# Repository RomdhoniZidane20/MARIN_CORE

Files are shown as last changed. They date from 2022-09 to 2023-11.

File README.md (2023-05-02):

# MARIN Core
ICHIRO Controller Manager Board for Dynamixel
## Features

* RS485/TTL on 4 Buses
* BNO055 IMU Sensor With Absolute Orientation
* Hot Swap switching System for Mini PC (Intel NUC 10th)
* Motor Voltage Power Switch System

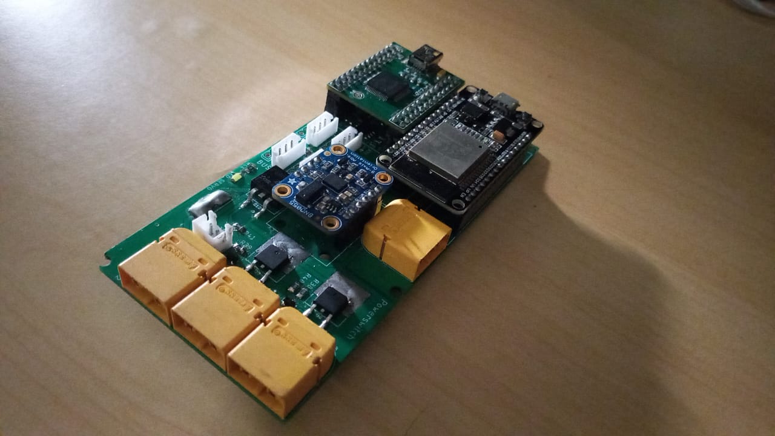
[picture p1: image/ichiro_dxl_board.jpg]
ichiro_dxl_board ICHIRO_DXL_BOARD


## Include Hardware and Software setup for dxl_board

Documentations for [FT4232_dxl](https://github.com/RomdhoniZidane20/ichiro_dxl_board/tree/main/firmware/FT4232)

Documentations for [MARIN_CORE](https://github.com/RomdhoniZidane20/ichiro_dxl_board/tree/main/firmware/Marin_Core_Firmware)

Documentations for [Loadcel_dxl](https://github.com/RomdhoniZidane20/ichiro_dxl_board/tree/main/firmware/Loadcell)

Documentations for [Interface_dxl](https://github.com/RomdhoniZidane20/ichiro_dxl_board/tree/main/firmware/Interface)

## License 
The FT4232 and ADM3078E eagle library of this repository based on 
"SUSTAINA-OP" by [Masato Kubotera](https://github.com/MasatoKubotera) is licensed under [ CC BY-NC-SA 4.0](https://creativecommons.org/licenses/by-nc-sa/4.0/).

CC BY-NC-SA 4.0


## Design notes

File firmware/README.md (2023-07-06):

# NOTE MASTER

## 15 September 2022

    1. Untuk program slave saat ini masih belum bisa bulkread maupun syncwrite  !!!
    2. Testing dengan protocol1.0 .
    3. Bulkread maupun snycwrite ditanggulani oleh latency timer usb menjadi 1 ms, maksimal latency yang bisa dicapai hingga 0 ms. (command : $ echo 1 | sudo tee /sys/bus/usb-serial/devices/ttyUSB0/latency_timer).
    4. Servo tidak bisa menjadi satu bus dengan slave esp karena akan terjadi masalah jika daya servo fail atau mati, paket akan error dan mengganggu paket yang dikirim oleh slave ke master (PC).
    
## 17 Januari 2023
    1. Slave BulkRead pada dynamixel2arduino slave upgrade memiliki maksimal panjang len address 6 byte. (PADA PROTOCOL 1.0)
    2. Jika bulkread address khusus read harus urut
    3. BELUM SUPPORT SYNCWRITE

## 25 Januari 2023
    1. Bulkread hanya bisa dibaca pada satu variabel array yang sama.
    2. Agar dapat dibaca Bulkread, pengiriman data paket dari firmware harus melalui satu array untuk pembacaan datanya.
    3. Sudah dapat membaca lebih dari 12 len address. 
    4. TODO syncwrite !!

## 6 Juli 2023
    1. Device Slave pada Dyanmixel2Arduino memiliki Return Delay sekitar 500us - 700us.
    2. TODO : mengecek berbagai rangkaian hardwware -> 1. Test pada ESP32 dengan Logic Level Converter
                                                       2. Test pada ESP32 dengan rankaian pembagi tegangan
                                                       3. Test pada ESP32 v4.
                                                       4. Test pada STM32 Blackpill.

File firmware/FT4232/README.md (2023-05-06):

# FIRMWARE

## Flash to correct EEPROM:
Install drivers from https://www.ftdichip.com/Drivers/D2XX.htm 

Unpack them:
```tar -xvf libftd2xx-x86_64-1.4.xx.gz```

Copy them into the library folder:
```sudo cp -r release/build/lib* /usr/local/lib```

Link them:
```sudo ln -s /usr/local/lib/libftd2xx.so.1.4.xx /usr/local/lib/libftd2xx.so```

Make them executable:
```sudo chmod 0755 /usr/local/lib/libftd2xx.so.1.4.xx```

Unload Serial USB Drivers (these will be reloaded when the device is removed and plugged back in)
```sudo rmmod ftdi_sio usbserial ```

compile code (in the firmware directory):
```gcc -o write main.c -L. -lftd2xx -Wl,-rpath,/usr/local/lib```

remove and plug in the device and it should appear as 4 virtual serial ports

## Source
This Firmware based on Bit-Bots [QUADDXL](https://github.com/bit-bots/bitbots_quaddxl) repository.

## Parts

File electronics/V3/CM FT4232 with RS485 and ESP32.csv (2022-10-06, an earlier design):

Qty | Value | Device | Package | Parts | Description | AVAILABILITY | DESCRIPTION | MF | MP | MPN | OC_FARNELL | OC_NEWARK | PACKAGE | POPULARITY | PRICE | PROD_ID | PURCHASE-URL | SPICEPREFIX | VALUE
2 |  | LEDCHIPLED_0805 | CHIPLED_0805 | LED_PC, LED_SERVO | LED |  |  |  |  |  |  |  |  | 52
37 |  | RESISTOR0805 | 0805 | R1, R2, R3, R4, R5, R6, R7, R8, R9, R10, R11, R12, R13, R14, R15, R16, R17, R18, R19, R20, R21, R22, R23, R24, R25, R26, R27, R28, R29, R30, R31, R32, R33, R34, R35, R36, R37 | Generic Resistor Package
1 | 100uF | CPOL-EU153CLV-1010 | 153CLV-1010 | C5 | POLARIZED CAPACITOR, European symbol |  |  |  |  |  |  |  |  | 0 |  |  |  | C
5 | 10K | R-US_M0805 | M0805 | R38, R39, R40, R41, R43 | RESISTOR, American symbol |  |  |  |  |  |  |  |  | 45 |  |  |  | R
2 | 1808_FUSE_HOLDER | 1808_FUSE_HOLDER | 1808_FUSE_HOLDER | U$3, U$4
1 | 1K | R-EU_R1206 | R1206 | R46 | RESISTOR, European symbol |  |  |  |  |  |  |  |  | 41 |  |  |  | R
2 | 200mA/40V | TRANS_PNP-PMBT3906|MMBT3906L | SOT23-3 | Q10, Q11 | PNP transistor |  |  |  |  |  |  |  |  |  |  | TRANS-08052 |  |  | 200mA/40V
4 | 22-03-5035 | 22-03-5035 | 5267-3 | J1, J2, J3, J4 | Molex SPOX Vert, Tin (Dynamixel AX/MX Bus)
4 | 22-03-5045 | 22-03-5045 | 5267-4 | J5, J6, J7, J8 | Molex SPOX Vert, Tin (Dynamixel RX Bus)
1 | 22-23-2021 | 22-23-2021 | 22-23-2021 | X8 | .100 (2.54mm) Center Header - 2 Pin" |  |  | MOLEX |  | 22-23-2021 | 1462926 | 25C3832 |  | 40
1 | 22-23-2041 | 22-23-2041 | 22-23-2041 | X1 | .100 (2.54mm) Center Header - 4 Pin" |  |  | MOLEX |  | 22-23-2041 | 1462920 | 38C0355 |  | 21
1 | 22-23-2071 | 22-23-2071 | 22-23-2071 | X2 | .100 (2.54mm) Center Header - 7 Pin" |  |  | MOLEX |  | 22-23-2071 | 1654534 | 56H0445 |  | 1
1 | 220uF | CPOL-EUUD-6,3X8,8 | UD-6,3X5,8_NICHICON | C6 | POLARIZED CAPACITOR, European symbol |  |  |  |  |  |  |  |  | 0 |  |  |  | C
2 | 2K | R-US_M0805 | M0805 | R42, R44 | RESISTOR, American symbol |  |  |  |  |  |  |  |  | 45 |  |  |  | R
1 | 33uH | CDRH127/LDNP-470MC | IND_CDRH127/LDNP-470MC_SUM | L1 | Check availability | In Stock | 47 µH Shielded - Inductor 3.25 A 78mOhm Max Nonstandard | Sumida America | CDRH127/LDNP-470MC |  |  |  | Nonstandard Sumida |  | None |  | https://pricing.snapeda.com/search/part/CDRH127/LDNP-470MC/?ref=eda
1 | 3K | R-EU_R1206 | R1206 | R45 | RESISTOR, European symbol |  |  |  |  |  |  |  |  | 41 |  |  |  | R
1 | 600mA/40V | TRANS_NPN-MMBT2222AL | SOT23-3 | Q1 | NPN transistor |  |  |  |  |  |  |  |  |  |  | TRANS-08049 |  |  | 600mA/40V
5 | ADM3078E | ADM3078E | ADM3078E | IC1, IC2, IC3, IC4, IC5
1 | BNO055 | BNO055 | BNO055 | U$2
1 | BOB-12009 | BOB-12009 | CONV_BOB-12009 | U2 | Logic Level Converter - Bi-Direc Check availability | In Stock | BSS138 Logic-Level Translator Interface Evaluation Board | SparkFun | BOB-12009 |  |  |  | None |  | None |  | https://pricing.snapeda.com/search/part/BOB-12009/?ref=eda
1 | ESP32DEVKITV1 | ESP32DEVKITV1 | ESP32-DEVKITV1 | U$1
1 | FT4232H_MINI_MODULE | FT4232H_MINI_MODULE | FT4232H_MINI_MODULE | M1
1 | LM2596S | LM2596S | TO263-5 | IC6 | SIMPLE SWITCHER® Power Converter 150 kHz 3A Step-Down Voltage Regulator |  |  | NATIONAL SEMICONDUCTOR |  | LM2596S-ADJ/NOPB | 9494367 | 41K3842 |  | 12
4 | SQM40P10-40L_GE3 | SQM40P10-40L_GE3 | TO-252-3 | Q7, Q8, Q9, Q12
1 | SS34 | SS34 | DIOM6859X262N | D1 | Check availability | In Stock | 3A, 40V, Schottky Rectifier | Taiwan Semiconductor | SS34 |  |  |  | SMC-2 Taiwan Semiconductor |  | None |  | https://pricing.snapeda.com/search/part/SS34/?ref=eda
4 | XT60PW-M | XT60PW-M | XT60PW-M | BATT_3, BATT_4, BATT_CM1, PC1

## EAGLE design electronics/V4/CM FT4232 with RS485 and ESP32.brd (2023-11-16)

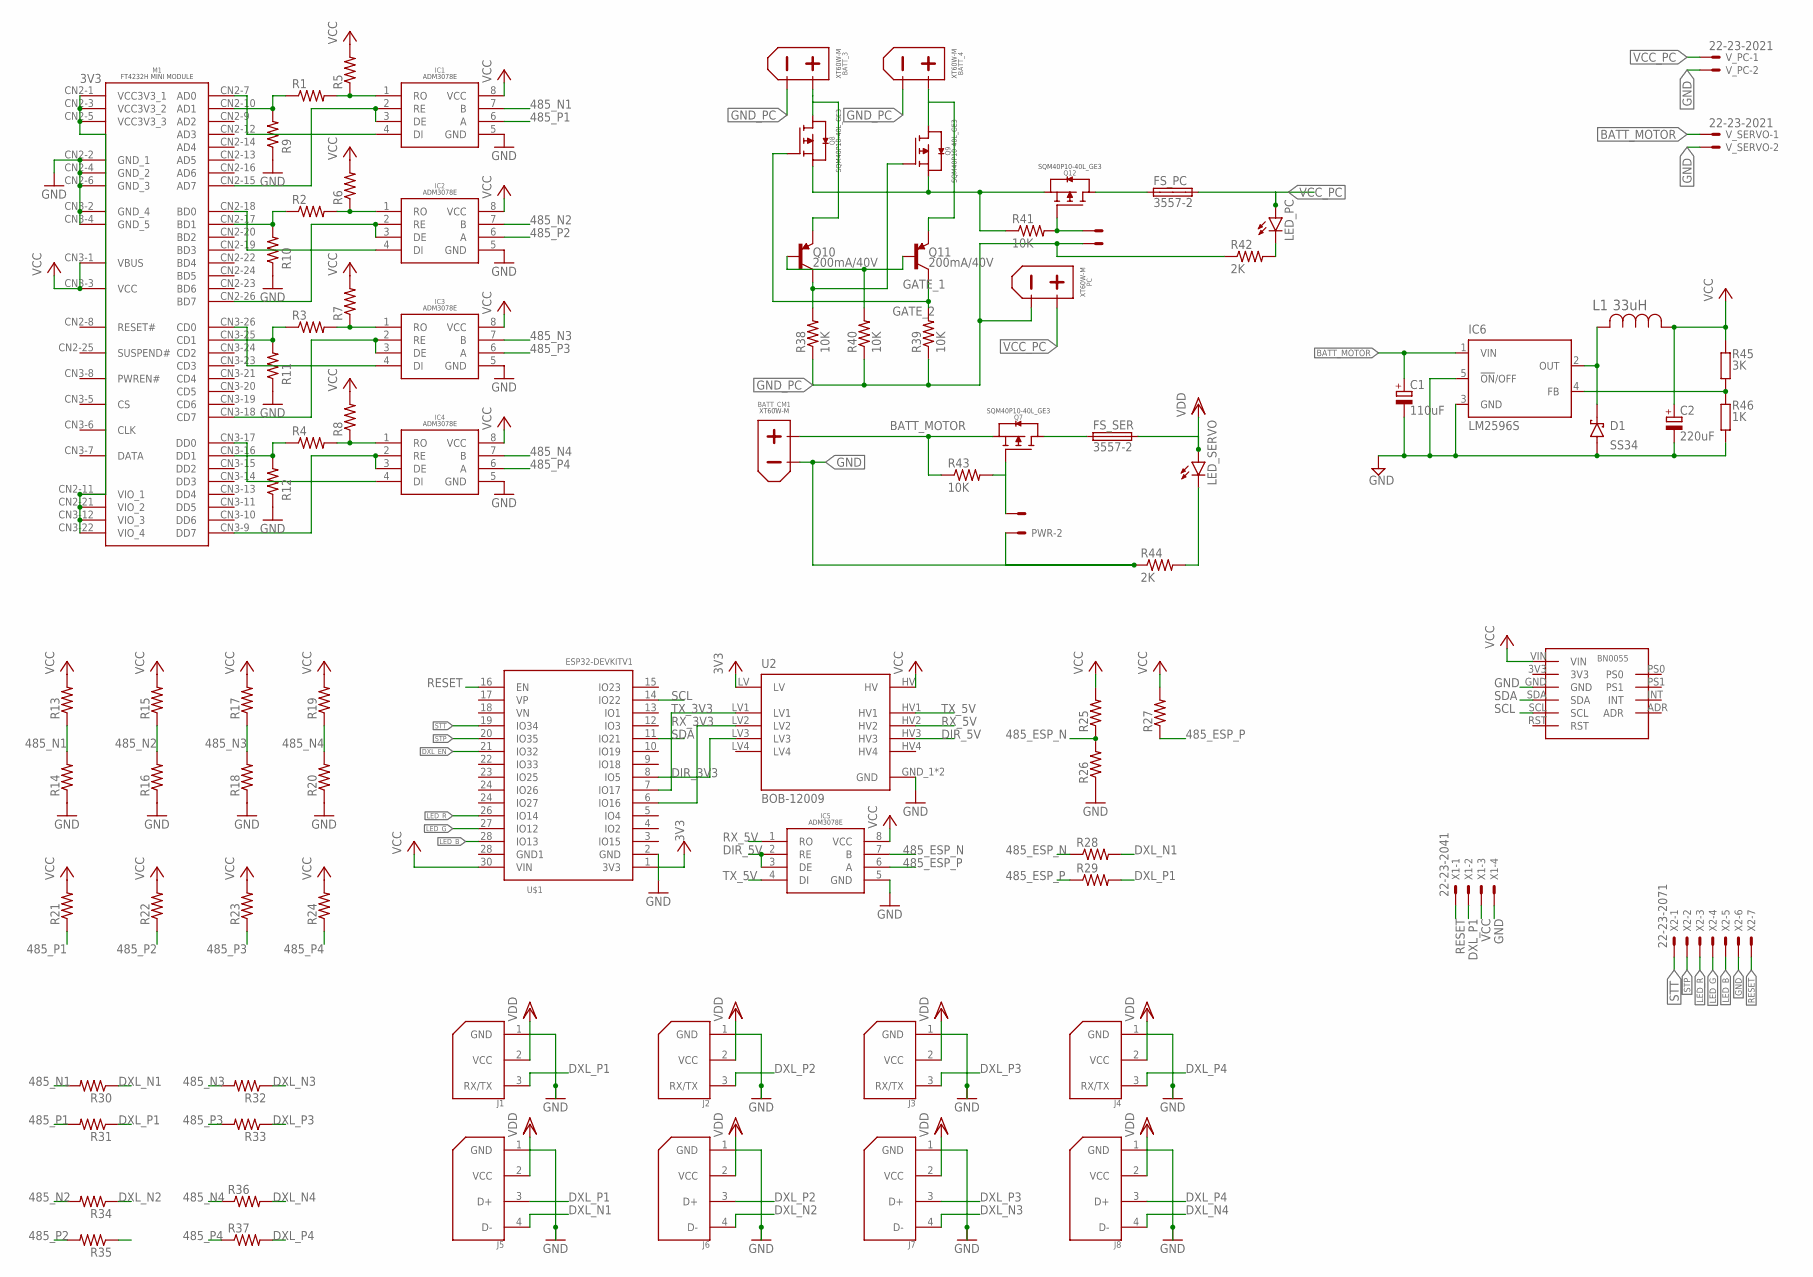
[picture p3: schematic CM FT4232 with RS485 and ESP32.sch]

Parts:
BATT_3, BATT_4: XT60PW-M
BATT_CM1: XT60PW-M
C1: 110uF; E2,5-6
C2: 220uF; E2,5-6
D1: SS34; DIOM6859X262N
FS_PC: 3557-2; FUSE_3557-2
FS_SER: 3557-2; FUSE_3557-2
IC1, IC2, IC3, IC4, IC5: ADM3078E
IC6: LM2596S; TO263-5
J1, J2, J3, J4: 22-03-5035; 5267-3
J5, J6, J7, J8: 22-03-5045; 5267-4
L1: 33uH; IND_CDRH127/LDNP-470MC_SUM
LED_PC: LEDCHIPLED_0805; CHIPLED_0805
LED_SERVO: LEDCHIPLED_0805; CHIPLED_0805
M1: FT4232H_MINI_MODULE
PC: XT60PW-M
PWR: 22-23-2021
Q7, Q8, Q9, Q12: SQM40P10-40L_GE3; TO-252-3
Q10, Q11: 200mA/40V; SOT23-3
R1, R2, R3, R4, R5, R6, R7, R8, R9, R10, R11, R12, R13, R14, R15, R16, R17, R18, R19, R20, R21, R22, R23, R24, R25, R26, R27, R28, R29, R30, R31, R32, R33, R34, R35, R36, R37: 0805
R38, R39, R40, R41, R43: 10K; M0805
R42, R44: 2K; M0805
R45: 3K; R1206
R46: 1K; R1206
SW_PC: 22-23-2021
U2: BOB-12009; CONV_BOB-12009
U$1: ESP32DEVKITV1; ESP32-DEVKITV1
U$2: BNO055
V_PC: 22-23-2021
V_SERVO: 22-23-2021
X1: 22-23-2041
X2: 22-23-2071

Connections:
3V3: M1.CN2-1 (VCC3V3_1), M1.CN2-3 (VCC3V3_2), M1.CN2-5 (VCC3V3_3), M1.CN2-11 (VIO_1), M1.CN2-21 (VIO_2), M1.CN3-12 (VIO_3), M1.CN3-22 (VIO_4), U2.LV, U$1.1 (3V3)
485_ESP_N: IC5.7 (B), R25.1, R26.2, R28.1
485_ESP_P: IC5.6 (A), R27.1, R29.1
485_N1: IC1.7 (B), R13.1, R14.2, R30.2
485_N2: IC2.7 (B), R15.1, R16.2, R34.2
485_N3: IC3.7 (B), R17.1, R18.2, R32.2
485_N4: IC4.7 (B), R19.1, R20.2, R36.1
485_P1: IC1.6 (A), R21.1, R31.2
485_P2: IC2.6 (A), R22.1, R35.2
485_P3: IC3.6 (A), R23.1, R33.2
485_P4: IC4.6 (A), R24.1, R37.1
+3: Q8.3 (S), Q9.3 (S), Q12.3 (S), R41.1
BATT_MOTOR: BATT_CM1.+, C1.+, IC6.1 (VIN), Q7.3 (S), R43.1, V_SERVO.1
DI1: IC1.4 (DI), M1.CN2-7 (AD0)
DIR_3V3: U2.LV3, U$1.8 (IO5)
DIR_5V: IC5.2 (RE), IC5.3 (DE), U2.HV3
DXL_EN: U$1.21 (IO32)
DXL_N1: J5.4 (D-), R28.2, R30.1
DXL_N2: J6.4 (D-), R34.1
DXL_N3: J7.4 (D-), R32.1
DXL_N4: J8.4 (D-), R36.2
DXL_P1: J1.3 (RX/TX), J5.3 (D+), R29.2, R31.1, X1.2
DXL_P2: J2.3 (RX/TX), J6.3 (D+), R35.1
DXL_P3: J3.3 (RX/TX), J7.3 (D+), R33.1
DXL_P4: J4.3 (RX/TX), J8.3 (D+), R37.2
GATE_1: Q9.1 (G), Q10.3 (C), R38.2
GATE_2: Q8.1 (G), Q11.3 (C), R39.2
GND: BATT_CM1.1 (-), BATT_CM1.2 (-), BATT_CM1.-, C1.-, C2.-, D1.A, IC1.5 (GND), IC2.5 (GND), IC3.5 (GND), IC4.5 (GND), IC5.5 (GND), IC6.3 (GND), IC6.5 (!ON!/OFF), J1.1 (GND), J2.1 (GND), J3.1 (GND), J4.1 (GND), J5.1 (GND), J6.1 (GND), J7.1 (GND), J8.1 (GND), M1.CN2-2 (GND_1), M1.CN2-4 (GND_2), M1.CN2-6 (GND_3), M1.CN3-2 (GND_4), M1.CN3-4 (GND_5), PWR.2, R9.1, R10.1, R11.1, R12.1, R14.1, R16.1, R18.1, R20.1, R26.1, R44.1, R46.1, U2.GND_1 (GND), U2.GND_2 (GND), U$1.2 (GND), U$2.GND, V_PC.2, V_SERVO.2, X1.4, X2.6
GND_PC: BATT_3.1 (-), BATT_3.2 (-), BATT_3.-, BATT_4.1 (-), BATT_4.2 (-), BATT_4.-, PC.1 (-), PC.2 (-), PC.-, R38.1, R39.1, R40.1, R42.1, SW_PC.2
LED_B: U$1.28 (IO13), X2.5
LED_G: U$1.27 (IO12), X2.4
LED_R: U$1.26 (IO14), X2.3
unnamed: FS_PC.1 (1A), Q12.4 (D)
unnamed: IC2.2 (RE), IC2.3 (DE), M1.CN2-26 (BD7)
unnamed: IC3.2 (RE), IC3.3 (DE), M1.CN3-18 (CD7)
unnamed: IC4.2 (RE), IC4.3 (DE), M1.CN3-9 (DD7)
unnamed: M1.CN2-10 (AD1), R1.1, R9.2
unnamed: FS_SER.1 (1A), Q7.4 (D)
unnamed: M1.CN2-17 (BD1), R2.1, R10.2
unnamed: IC2.1 (RO), R2.2, R6.1
unnamed: IC3.1 (RO), R3.2, R7.1
unnamed: M1.CN3-25 (CD1), R3.1, R11.2
unnamed: M1.CN3-16 (DD1), R4.1, R12.2
unnamed: IC4.1 (RO), R4.2, R8.1
unnamed: IC2.4 (DI), M1.CN2-18 (BD0)
unnamed: IC3.4 (DI), M1.CN3-26 (CD0)
unnamed: IC4.4 (DI), M1.CN3-17 (DD0)
unnamed: BATT_3.+, Q8.4 (D), Q10.2 (E)
unnamed: BATT_4.+, Q9.4 (D), Q11.2 (E)
unnamed: Q10.1 (B), Q11.1 (B), R40.2
unnamed: Q12.1 (G), R41.2, SW_PC.1
unnamed: PWR.1, Q7.1 (G), R43.2
unnamed: LED_PC.C, R42.2
unnamed: LED_SERVO.C, R44.2
unnamed: IC6.4 (FB), R45.1, R46.2
unnamed: D1.C (K), IC6.2 (OUT), L1.2
RE1: IC1.2 (RE), IC1.3 (DE), M1.CN2-15 (AD7)
RESET: U$1.16 (EN), X1.1, X2.7
RO1: IC1.1 (RO), R1.2, R5.1
RX_3V3: U2.LV2, U$1.6 (IO16)
RX_5V: IC5.1 (RO), U2.HV2
SCL: U$1.14 (IO22), U$2.SCL
SDA: U$1.11 (IO21), U$2.SDA
STP: U$1.20 (IO35), X2.2
STT: U$1.19 (IO34), X2.1
TX_3V3: U2.LV1, U$1.7 (IO17)
TX_5V: IC5.4 (DI), U2.HV1
VCC: C2.+, IC1.8 (VCC), IC2.8 (VCC), IC3.8 (VCC), IC4.8 (VCC), IC5.8 (VCC), L1.1, M1.CN3-1 (VBUS), M1.CN3-3 (VCC), R5.2, R6.2, R7.2, R8.2, R13.2, R15.2, R17.2, R19.2, R21.2, R22.2, R23.2, R24.2, R25.2, R27.2, R45.2, U2.HV, U$1.30 (VIN), U$2.VIN, X1.3
VCC_PC: FS_PC.3 (2A), LED_PC.A, PC.+, V_PC.1
VDD: FS_SER.3 (2A), J1.2 (VCC), J2.2 (VCC), J3.2 (VCC), J4.2 (VCC), J5.2 (VCC), J6.2 (VCC), J7.2 (VCC), J8.2 (VCC), LED_SERVO.A

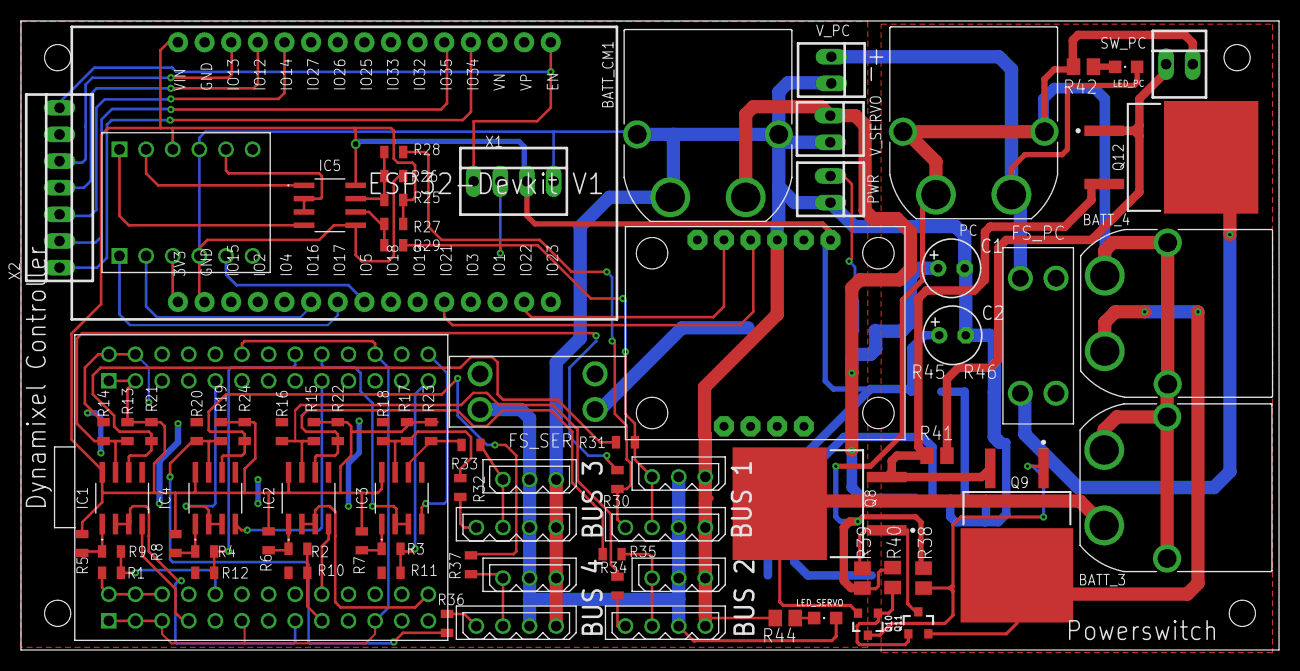
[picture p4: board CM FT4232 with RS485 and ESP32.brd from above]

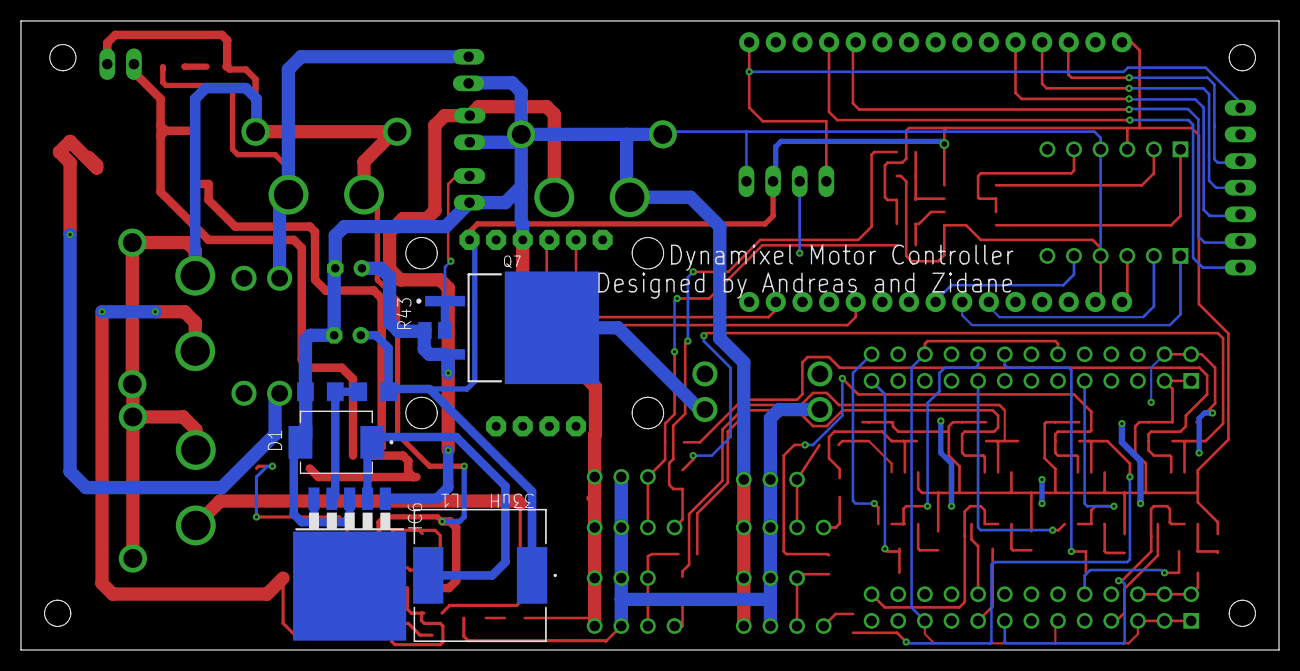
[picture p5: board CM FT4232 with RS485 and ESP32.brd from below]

Board: 2 copper layers, 120.0 x 60.0 mm, 88 parts (7 on the bottom side), 69 nets.

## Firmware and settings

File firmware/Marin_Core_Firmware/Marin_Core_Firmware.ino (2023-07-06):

#include <Dynamixel2Arduino.h>
#include <Wire.h>
#include <Adafruit_Sensor.h>
#include <Adafruit_BNO055.h>
#include <utility/imumaths.h>

TaskHandle_t task_dxl, task_input;

void Task_DXL( void *pvParameters );
void Task_INPUT( void *pvParameters );

//IMU variables
uint16_t BNO055_SAMPLERATE_DELAY_MS = 0;


// Dynamixel Arduino define pin for CM
#define DXL_SERIAL               Serial2
#define DEBUG_SERIAL             Serial
const uint8_t DXL_DIR_PIN =      5;
const uint8_t DXL_ID      =      200; // ID Dynamixel

// Pinout for Switch
#define SW_Start                 35
#define SW_Stop                  34
#define Dxl_power                32

// Pinout for LED
#define LED_Red_enable           12
#define LED_Green_enable         13
#define LED_Blue_enable          14

//State
//#define Return_Delay             2
//volatile int start_button_state = 0;
//volatile int stop_button_state  = 0;

//Dynamixel Arduino porthandler and packethandler
DYNAMIXEL::SerialPortHandler dxl_port(DXL_SERIAL, DXL_DIR_PIN);
const float DXL_PROTOCOL_VER_1_0 = 1.0;
const float DXL_PROTOCOL_VER_2_0 = 2.0;
const uint16_t DXL_MODEL_NUM     = 0x190; // OpenCM 9.04 model number
DYNAMIXEL::Slave dxl(dxl_port, DXL_MODEL_NUM);

// Addresses for read register variable
uint8_t Yaw_addr         = 66;
uint8_t Pitch_addr       = 68;
uint8_t Roll_addr        = 70;
uint8_t SW_Start_addr    = 72;
uint8_t SW_Stop_addr     = 74;
uint8_t AccelX_addr      = 76;
uint8_t AccelY_addr      = 78;
uint8_t AccelZ_addr      = 80;
uint8_t GyroX_addr       = 82;
uint8_t GyroY_addr       = 84;
uint8_t GyroZ_addr       = 86;

// Address for wirte register variable
uint8_t Reset_addr        = 88;
uint8_t dxl_enbale_addr   = 90;
uint8_t LED_R_addr        = 92;
uint8_t LED_G_addr        = 94;
uint8_t LED_B_addr        = 96;


// Stored variables for Interrupt
uint8_t Switch_Button[2];
uint8_t dxl_power_enable;

// Stored variable for imu
uint16_t dxl_data[20];
int32_t accel_raw[3];
int32_t gyro_raw[3];
int32_t temp;


//This namespace is required to use Control table item names
using namespace ControlTableItem;


void setup()
{
  DEBUG_SERIAL.begin(115200);
  disableCore0WDT();
  disableCore1WDT();

  xTaskCreatePinnedToCore(
    Task_DXL
    ,  "Task_DXL"   // task name
    ,  65536        // stack size allocations
    ,  NULL
    ,  3
    ,  &task_dxl
    ,  0);

  xTaskCreatePinnedToCore(
    Task_INPUT
    ,  "Task_INPUT"   // task name
    ,  65536          // stack size allocations
    ,  NULL
    ,  3
    ,  &task_input
    ,  1);

}

void loop()
{
  // skip this state
}

void Task_DXL( void *pvParameters )
{
  (void) pvParameters;

  dxl_port.begin(1000000);
  dxl.setPortProtocolVersion(DXL_PROTOCOL_VER_1_0);
  dxl.setFirmwareVersion(41);
  dxl.setID(DXL_ID);

  dxl.addControlItem(Yaw_addr,        dxl_data[0]);
  dxl.addControlItem(Pitch_addr,      dxl_data[1]);
  dxl.addControlItem(Roll_addr,       dxl_data[2]);
  dxl.addControlItem(SW_Start_addr,   dxl_data[3]);
  dxl.addControlItem(SW_Stop_addr,    dxl_data[4]);
  dxl.addControlItem(AccelX_addr,     dxl_data[5]);
  dxl.addControlItem(AccelY_addr,     dxl_data[6]);
  dxl.addControlItem(AccelZ_addr,     dxl_data[7]);
  dxl.addControlItem(GyroX_addr,      dxl_data[8]);
  dxl.addControlItem(GyroY_addr,      dxl_data[9]);
  dxl.addControlItem(GyroZ_addr,      dxl_data[10]);
  dxl.addControlItem(Reset_addr,      dxl_data[11]);
  dxl.addControlItem(dxl_enbale_addr, dxl_data[12]);
  dxl.addControlItem(LED_R_addr,      dxl_data[13]);
  dxl.addControlItem(LED_G_addr,      dxl_data[14]);
  dxl.addControlItem(LED_B_addr,      dxl_data[15]);

  dxl.setReadCallbackFunc(read_callback_func);
  dxl.setWriteCallbackFunc(write_callback_func);

  for (;;)
  {
    if (dxl.processPacket() == false) {

      DEBUG_SERIAL.print("Last lib err code: ");
      DEBUG_SERIAL.print(dxl.getLastLibErrCode());
      DEBUG_SERIAL.print(", ");
      DEBUG_SERIAL.print("Last status packet err code: ");
      DEBUG_SERIAL.println(dxl.getLastStatusPacketError());
      DEBUG_SERIAL.println();

    }

  }

}

void read_callback_func(uint16_t item_addr, uint8_t &dxl_err_code, void* arg)
{
  (void)dxl_err_code, (void)arg;

  if (item_addr == Yaw_addr)
  {
    dxl_data[0];
  }

  else if (item_addr == Pitch_addr)
  {
    dxl_data[1];
  }

  else if (item_addr == Roll_addr)
  {
    dxl_data[2];
  }

  else if (item_addr == SW_Start_addr)
  {
    dxl_data[3];
  }

  else if (item_addr == SW_Stop_addr)
  {
    dxl_data[4];
  }

  else if (item_addr == AccelX_addr)
  {
    dxl_data[5];
  }

  else if (item_addr == AccelY_addr)
  {
    dxl_data[6];
  }

  else if (item_addr == AccelZ_addr)
  {
    dxl_data[7];
  }

  else if (item_addr == GyroX_addr)
  {
    dxl_data[8];
  }

  else if (item_addr == GyroY_addr)
  {
    dxl_data[9];
  }

  else if (item_addr == GyroZ_addr)
  {
    dxl_data[10];
  }

}


void write_callback_func(uint16_t item_addr, uint8_t &dxl_err_code, void* arg)
{
  (void)dxl_err_code, (void)arg;

  if (item_addr == Reset_addr)
  {
    if (dxl_data[11] == 1)
    {
      ESP.restart();
    }

  }
  if (item_addr == dxl_enbale_addr)
  {

    digitalWrite(Dxl_power, dxl_data[12]);
  }

  else if (item_addr == LED_R_addr)
  {
    digitalWrite(LED_Red_enable, dxl_data[13]);
  }

  else if (item_addr == LED_G_addr)
  {
    digitalWrite(LED_Green_enable, dxl_data[14]);
  }

  else if (item_addr == LED_B_addr)
  {
    digitalWrite(LED_Blue_enable, dxl_data[15]);
  }
}


void Task_INPUT( void *pvParameters )
{
  (void) pvParameters;
  Adafruit_BNO055 bno = Adafruit_BNO055(55, 0x28);

  bno.begin(bno.OPERATION_MODE_IMUPLUS);

  pinMode(SW_Start, INPUT);
  pinMode(SW_Stop, INPUT);
  pinMode(Dxl_power, OUTPUT);
  pinMode(LED_Red_enable, OUTPUT);
  pinMode(LED_Green_enable, OUTPUT);
  pinMode(LED_Blue_enable, OUTPUT);

  for (;;)
  {
    imu::Vector<3> Orientation = bno.getVector(Adafruit_BNO055::VECTOR_EULER);
    imu::Vector<3> Accel       = bno.getVector(Adafruit_BNO055::VECTOR_LINEARACCEL);
    imu::Vector<3> Gyro        = bno.getVector(Adafruit_BNO055::VECTOR_GYROSCOPE);

    //  YPR value
    dxl_data[0]  = Orientation.x() + 1000;
    dxl_data[1]  = Orientation.z() + 1000;
    dxl_data[2]  = Orientation.y() + 1000;

    // Push Button Start & Stop
    dxl_data[3] = digitalRead(SW_Start);
    dxl_data[4] = digitalRead(SW_Stop);
    

    //  Accelerometer Value
    accel_raw[0] = Accel.y();
    accel_raw[1] = Accel.x();
    accel_raw[2] = Accel.z();

    temp = (accel_raw[0]);
    temp = temp * 5/2;
    temp = 512 + temp;
    if (temp > 1023) temp = 1023;
    if(temp < 0) temp = 0;
    dxl_data[5] = temp;

    temp = (accel_raw[1]);
    temp = temp * 5/2;
    temp = 512 + temp;
    if (temp > 1023) temp = 1023;
    if(temp < 0) temp = 0;
    dxl_data[6] = temp;

    temp = (accel_raw[2]);
    temp = temp * 5/2;
    temp = 512 + temp;
    if (temp > 1023) temp = 1023;
    if(temp < 0) temp = 0;
    dxl_data[7] = temp;

    //  Gyro Value
    gyro_raw[0] = Gyro.y();
    gyro_raw[1] = Gyro.x();
    gyro_raw[2] = Gyro.z();

    temp = (gyro_raw[0]);
    temp = temp * (-1);
    temp = 512 + temp;
    if (temp > 1023) temp = 1023;
    if (temp < 0) temp = 0;
    dxl_data[8] = temp;

    temp = (gyro_raw[1]);
    temp = temp * (-1);
    temp = 512 + temp;
    if (temp > 1023) temp = 1023;
    if (temp < 0) temp = 0;
    dxl_data[9] = temp;

    temp = (gyro_raw[2]);
    temp = temp ;
    temp = 512 + temp;
    if (temp > 1023) temp = 1023;
    if (temp < 0) temp = 0;
    dxl_data[10] = temp;  
    
    uint8_t system, gyro, accel = 0;
    bno.Calibration_no_mag(&system, &gyro, &accel);
  }

}

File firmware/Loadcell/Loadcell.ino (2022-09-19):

#include "ADS126X.h"
#include <array>
#include <Preferences.h>
#include <Dynamixel2Arduino.h>

// Dynamixel Arduino define pin for CM
#define DXL_SERIAL               Serial2
#define DEBUG_SERIAL             Serial
const uint8_t DXL_DIR_PIN =      5;
const uint8_t DXL_ID      =      200; // ID Dynamixel

// addresses for loadcell
uint16_t addr_force_1           = 60;
uint16_t addr_force_2           = 64;
uint16_t addr_force_3           = 68;
uint16_t addr_force_4           = 72;

//Dynamixel Arduino porthandler and packethandler
DYNAMIXEL::SerialPortHandler dxl_port(DXL_SERIAL, DXL_DIR_PIN);
const float DXL_PROTOCOL_VER_1_0 = 1.0;
const float DXL_PROTOCOL_VER_2_0 = 2.0;
const uint16_t DXL_MODEL_NUM     = 0x136; // OpenCM 9.04 model number
DYNAMIXEL::Slave dxl(dxl_port, DXL_MODEL_NUM);

// ADS126 define pin
ADS126X adc;
#define NUM_AVG 5 //number of samples to use for comparing the value to the median of the
#define ADS_CHIP_SELECT 5 // CS pin
#define ADS_RESET_PIN 4

// Stored variables for loadcell
std::array<uint16_t, 4> force;
std::array<uint8_t, 4> pos_pin;
std::array<uint8_t, 4> neg_pin;
std::array<std::array<int32_t, NUM_AVG>, 4> previous_values;

// cop variables
float dx = 1; // panjang titik tengah F1 dan F2 or F3 dan F4
float dy = 1; // lebar  titik tengah F1 dan F3 or F2 dan F4
float x  = 1; // diameter dalam pul ke luar plat bagian samping (X)
float y  = 1; // diametet dalam pul ke luar plat bagian atas/bawah (Y)


void setup() {

  DEBUG_SERIAL.begin(115200);
  init_ads();

  dxl_port.begin(1000000);
  dxl.setPortProtocolVersion(DXL_PROTOCOL_VER_1_0);
  dxl.setFirmwareVersion(25);
  dxl.setID(DXL_ID);

  dxl.addControlItem(addr_force_1, force[0]);
  dxl.addControlItem(addr_force_2, force[1]);
  dxl.addControlItem(addr_force_3, force[2]);
  dxl.addControlItem(addr_force_4, force[3]);

  dxl.setReadCallbackFunc(read_callback_func);


  // ads and loadcell
  pos_pin[0] = 7; //ADS126X_AIN7;
  pos_pin[1] = 5; //ADS126X_AIN5;
  pos_pin[2] = 3; //ADS126X_AIN3;
  pos_pin[3] = 1; //ADS126X_AIN1;

  neg_pin[0] = 6; //ADS126X_AIN6;
  neg_pin[1] = 4; //ADS126X_AIN4;
  neg_pin[2] = 2; //ADS126X_AIN2;
  neg_pin[3] = 0; //ADS126X_AIN0;


}

void loop() {

  if (dxl.processPacket() == false) {

    DEBUG_SERIAL.print("Last lib err code: ");
    DEBUG_SERIAL.print(dxl.getLastLibErrCode());
    DEBUG_SERIAL.print(", ");
    DEBUG_SERIAL.print("Last status packet err code: ");
    DEBUG_SERIAL.println(dxl.getLastStatusPacketError());
    DEBUG_SERIAL.println();

  }

  int current_sensor = 0;
  long count = 0;
  long counter = 0;

  adc.readADC1(pos_pin[current_sensor], neg_pin[current_sensor]);
  delayMicroseconds(250);

  uint16_t reading = adc.readADC1(pos_pin[current_sensor], neg_pin[current_sensor]);

  if (!reading || reading == 1) // detect if faulty reading occured
  {
    init_ads();
  }
  else if (reading == 0x1000000) //detect if reset occured
  {
    if (adc.checkResetBit())
    {
      init_ads();
    }
  }
  else
  {
    // sort to get median of previous values
    std::array<int32_t, NUM_AVG> current_previous = previous_values[current_sensor];
    std::sort(current_previous.begin(), current_previous.end());

    // check if current reading deviates too strongly from median
    if (abs(current_previous[NUM_AVG / 2] - reading) < 1e7)
    {
      force[current_sensor] = reading;
    }
    // update previous values for median calculation
    previous_values[current_sensor][count] = reading;

    // update current sensor
    current_sensor = (current_sensor + 1) % 4;

    // update counter for median calculating
    if (!current_sensor)
    {
      count = (count + 1) % NUM_AVG;
    }
  }


  //  long voltage1 = adc.readADC1(pos_pin[0], neg_pin[0]);
  //  long voltage2 = adc.readADC1(pos_pin[1], neg_pin[1]);
  //  long voltage3 = adc.readADC1(pos_pin[2], neg_pin[2]);
  //  long voltage4 = adc.readADC1(pos_pin[3], neg_pin[3]);
}

void init_ads()
{

  digitalWrite(4, LOW);
  delayMicroseconds(2);
  digitalWrite(4, HIGH);
  delayMicroseconds(4);

  adc.begin(ADS_CHIP_SELECT); // setup with chip select pin
  adc.setGain(ADS126X_GAIN_32);
  adc.setRate(ADS126X_RATE_38400);
  adc.setFilter(ADS126X_SINC4);
  adc.enableInternalReference();
  adc.startADC1(); // start conversion on ADC1

  adc.disableStatus();
  adc.disableCheck();
  adc.setDelay(ADS126X_DELAY_0);
  adc.clearResetBit();

}

void read_callback_func(uint16_t item_addr, uint8_t &dxl_err_code, void* arg)
{
  (void)dxl_err_code, (void)arg;

  if (item_addr == addr_force_1)
  {
    force[0];
  }

  if (item_addr == addr_force_2)
  {
    force[2];
  }

  if (item_addr == addr_force_3)
  {
    force[3];
  }

  if (item_addr == addr_force_4)
  {
    force[4];
  }
}

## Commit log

2022-08-27 add framework
2022-08-27 change framework to firmware
2022-08-28 fix overflow issues on IMU
2022-09-02 add sch, firmware add LED
    [CM_Prototype.brd, CM_Prototype.sch]
2022-09-10 sch and brd files revision
    [CM FT4232 with RS485 and ESP32.brd, CM FT4232 with RS485 and ESP32.sch, CM_Prototype.brd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]
2022-09-22 upload new revision design
    [CM FT4232 with RS485 and ESP32.brd, CM FT4232 with RS485 and ESP32.sch]
2022-10-06 add BOM files
    [CM FT4232 with RS485 and ESP32.csv]
2023-01-16 board testing
2023-01-24 insert array to dxl
2023-01-28 Add MARIN_CORE V4
    [CM FT4232 with RS485 and ESP32.brd, CM FT4232 with RS485 and ESP32.sch]
2023-03-08 add feature reset chip_dxl and LED
    [Marin_Core_Firmware.ino]
2023-03-12 Update README.md
    ICHIRO Controller Manager Board for Dynamixel
2023-03-15 add accel gyro data and rearanged address
2023-03-16 bulkread address bug fixed
    [Marin_Core_Firmware.ino]
2023-03-27 Implement dual core on MARIN CORE ESP32
2023-03-27 Implement Dual Core Marin Core ESP32
2023-04-12 fix: Update Gyro and Accel data
    [Marin_Core_Firmware.ino]
2023-04-19 fix: read callback function
    [Marin_Core_Firmware.ino]
2023-05-02 push button swap pinout
    [Marin_Core_Firmware.ino]
2023-11-16 add schematic drawer names
    [CM FT4232 with RS485 and ESP32.brd]
2023-11-16 add drawer names
    [CM FT4232 with RS485 and ESP32.brd]

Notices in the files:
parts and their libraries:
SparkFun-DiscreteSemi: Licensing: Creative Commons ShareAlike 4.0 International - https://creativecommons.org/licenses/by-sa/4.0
